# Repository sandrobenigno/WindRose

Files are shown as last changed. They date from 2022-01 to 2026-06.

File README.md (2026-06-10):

# The WindRose Project
Custom Hardware , Firmware and Software for Robotic Cellular Automata Experiments.

DOI (https://zenodo.org/badge/latestdoi/437105817)

### We’re used to hearing about evolution by competition, but what about thinking about things that evolve from cooperation?
<p>We can learn a lot about ourselves by simulating robotic beings communicating, sharing information, tools and interacting as a community of living beings. In these simulations, questions emerge such as the importance of synchronicity between beings, the need for a shared language for mutual understanding, among many other issues. That’s what this project and research is about.</p>

<p>Author: Sandro Benigno, due to the inspiration and all the applied resources from fellow professor Marilia Lyra Bergamo. She is the one who made this project possible and guided me with her research on Robotic Plants and Complexity Theories.</p>

### The Wiki Pages

<p>In the <a href="https://github.com/sandrobenigno/WindRose/wiki">wiki pages</a> you can learn about the board, including the pinout and its usage.</p>

### Code documentation
All the files and classes are <a target="_blank" rel="noopener noreferrer" href="https://sandrobenigno.github.io/WindRose/html/index.html">documented here</a>.

### Fabrication

<p>We fabricate the boards through Seeed Fusion PCB Assembly Service. Check how to <a href="https://github.com/sandrobenigno/WindRose/wiki/Fabricate-yours%21">fabricate yours!</a></p>

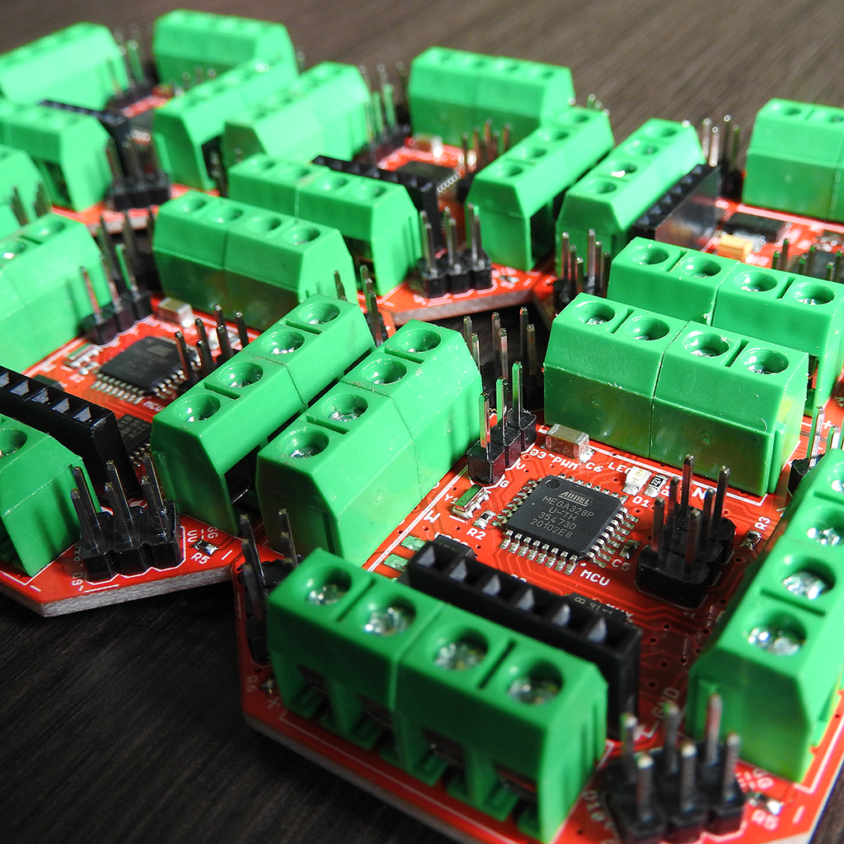
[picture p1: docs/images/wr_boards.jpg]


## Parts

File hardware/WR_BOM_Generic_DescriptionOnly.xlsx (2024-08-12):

Part | Value | Device | Package
C1 | 0.1uF | 0.1UF-0402-6.3V-10%-X7R | 0402
C2 | 47uF | 10UF-POLAR-EIA3216-16V-10%(TANT) | EIA3216
C3 | 0.1uF | 0.1UF-0402-6.3V-10%-X7R | 0402
C4 | 0.1uF | 0.1UF-0402-6.3V-10%-X7R | 0402
C5 | 0.1uF | 0.1UF-0402-6.3V-10%-X7R | 0402
C6 | 100uF | C-USC3216 | 3216
D1 | LED | LEDCHIP-LED0805 | 0805
D2 | SS24FL | DIODE-SOD123 | SOD123
MCU | ATMEGA328-AU | ATMEGA328-AU | QFP32_7X7_0.80
MUX | CD4051SSOP16 | CD4051SSOP16 | SSOP16
R1 | 220 | 220OHM-0603-1/10W-1% | 0603
R2 | 1M | R-US_R0402 | 0402
R3 | 10k | 10KOHM-0402-1/16W-1% | 0402
R4 | 10k | 10KOHM-0402-1/16W-1% | 0402
R5 | 10k | 10KOHM-0402-1/16W-1% | 0402
R6 | 10k | 10KOHM-0402-1/16W-1% | 0402
R7 | 10k | 10KOHM-0402-1/16W-1% | 0402
VREG |  | V_REG_AMS1117-5.0_SOT223 | SOT223
Y1 | 16MHz | RESONATOR-16MHZSMD_3.2X1.3 | RESONATOR-SMD-3.2X1.3

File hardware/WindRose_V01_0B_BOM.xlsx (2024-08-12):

Designator | Manufacturer Part Number or Seeed SKU | Qty | Link
C1,C3,C4,C5 | 302010037 | 4 | https://statics3.seeedstudio.com/fusion/opl/datasheet/302010037.pdf
C2 | 302020005 | 1 | https://statics3.seeedstudio.com/fusion/opl/datasheet/302020005.pdf
C6 | 302010183 | 1 | https://statics3.seeedstudio.com/fusion/opl/datasheet/302010183.pdf
D1 | 304090046 | 1 | https://statics3.seeedstudio.com/fusion/opl/datasheet/304090046.pdf
D2 | SS24FL | 1 | https://www.onsemi.com/pdf/datasheet/ss26fl-d.pdf
MCU | ATMEGA328P-AU | 1 | https://file.elecfans.com/web1/M00/BC/23/pIYBAF60v-CAX_3dAAs5XU5rfIc187.pdf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
MUX | CD4051BPWR | 1 | https://file.elecfans.com/web1/M00/9F/41/pIYBAF1AobyAUILsABdUm6BbdQU091.pdf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
R1 | RT0603DRD07220RL | 1 | https://file.elecfans.com/web2/M00/5A/77/poYBAGLrqhuANnZQAA8p9tNjF34381.pdf
R2 | 301010043 | 1 | https://statics3.seeedstudio.com/fusion/opl/datasheet/301010043.pdf
R3,R4,R5,R6,R7 | 301010047 | 5 | https://statics3.seeedstudio.com/fusion/opl/datasheet/301010047.pdf
VREG | AMS1117-5.0 | 1 | https://file.elecfans.com/web1/M00/8D/D9/o4YBAFyupoKAaMjDAALlu6SGvak196.pdf
Y1 | 306030002 | 1 | https://statics3.seeedstudio.com/fusion/opl/datasheet/306030002.pdf

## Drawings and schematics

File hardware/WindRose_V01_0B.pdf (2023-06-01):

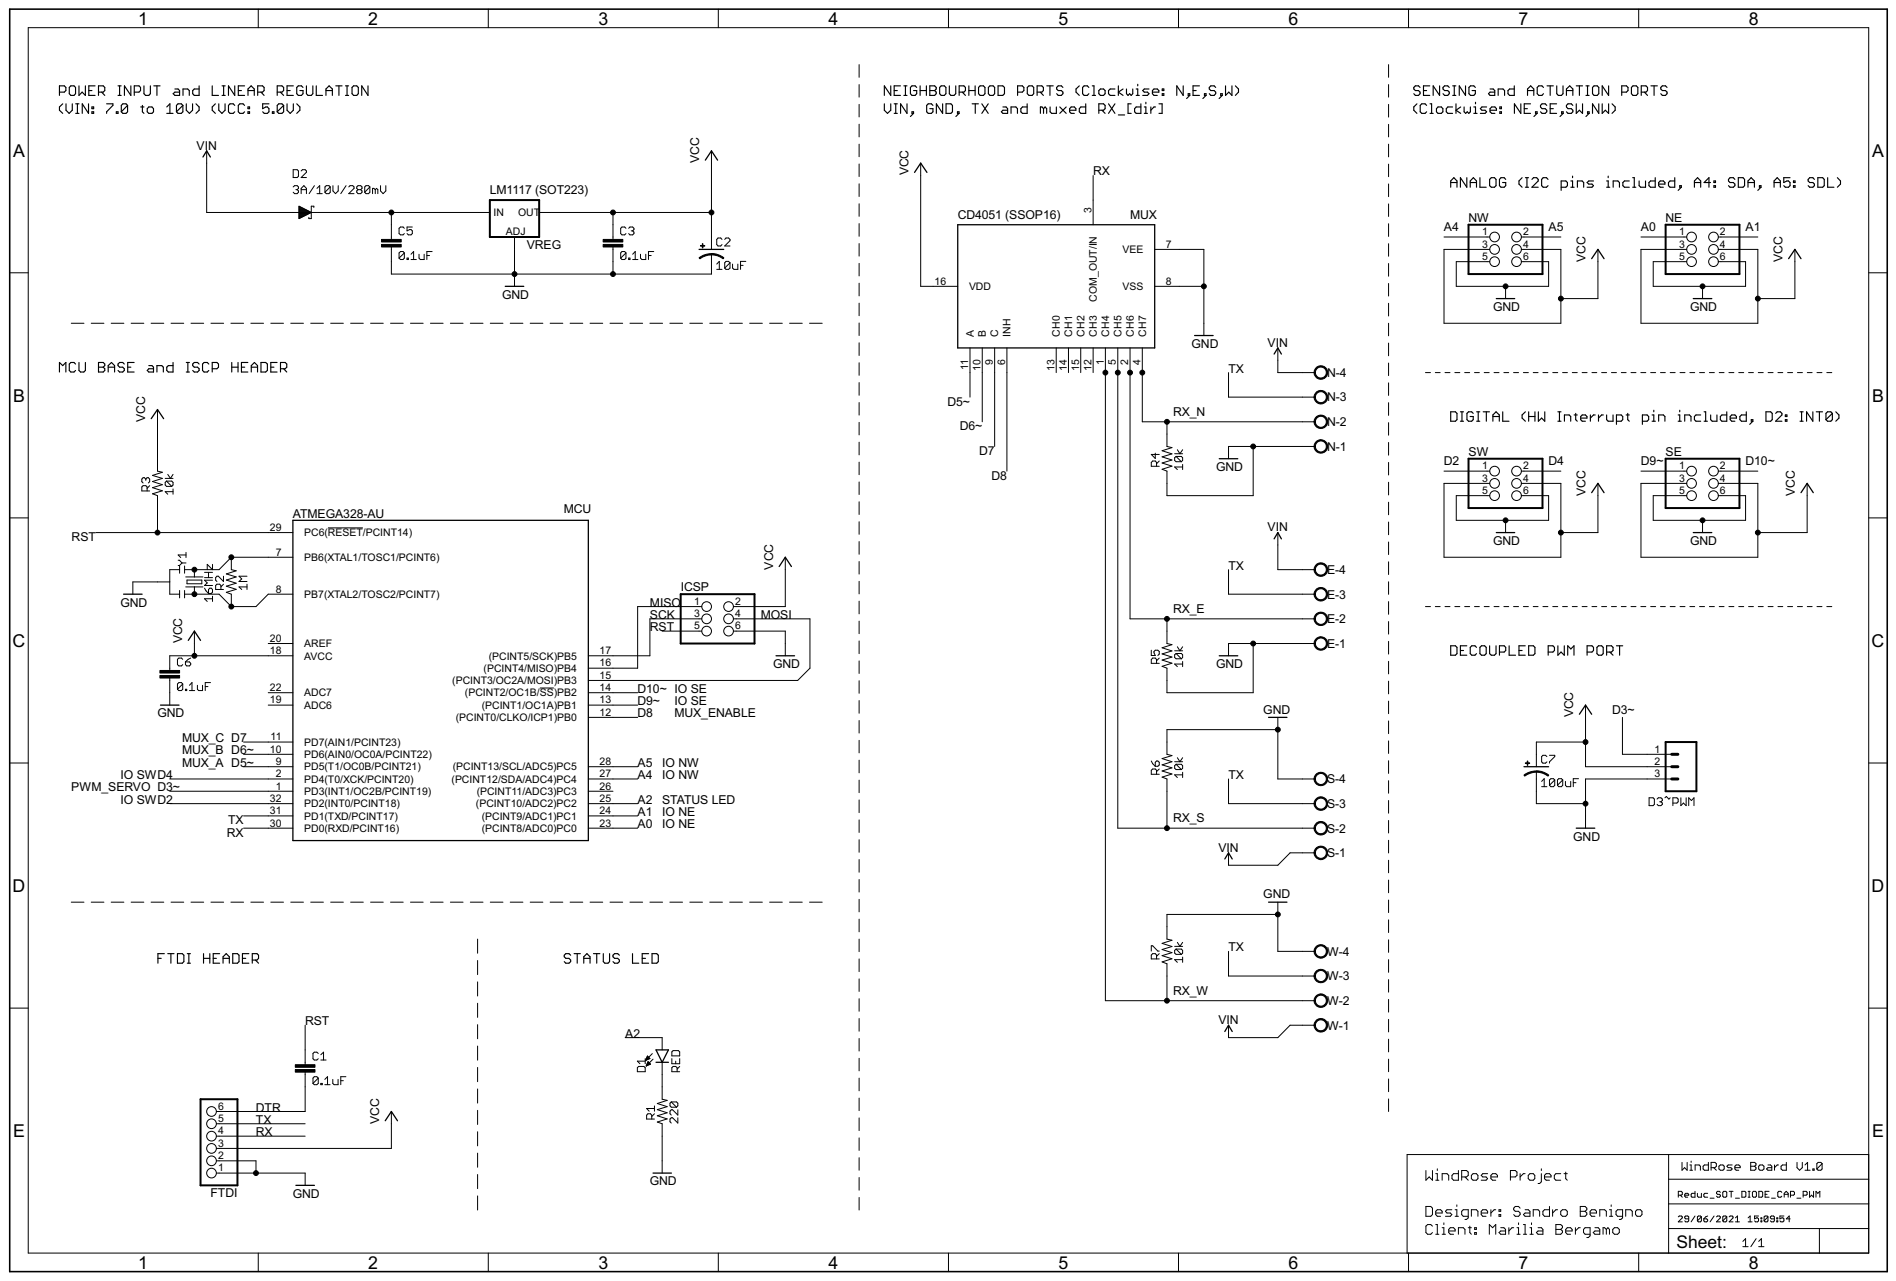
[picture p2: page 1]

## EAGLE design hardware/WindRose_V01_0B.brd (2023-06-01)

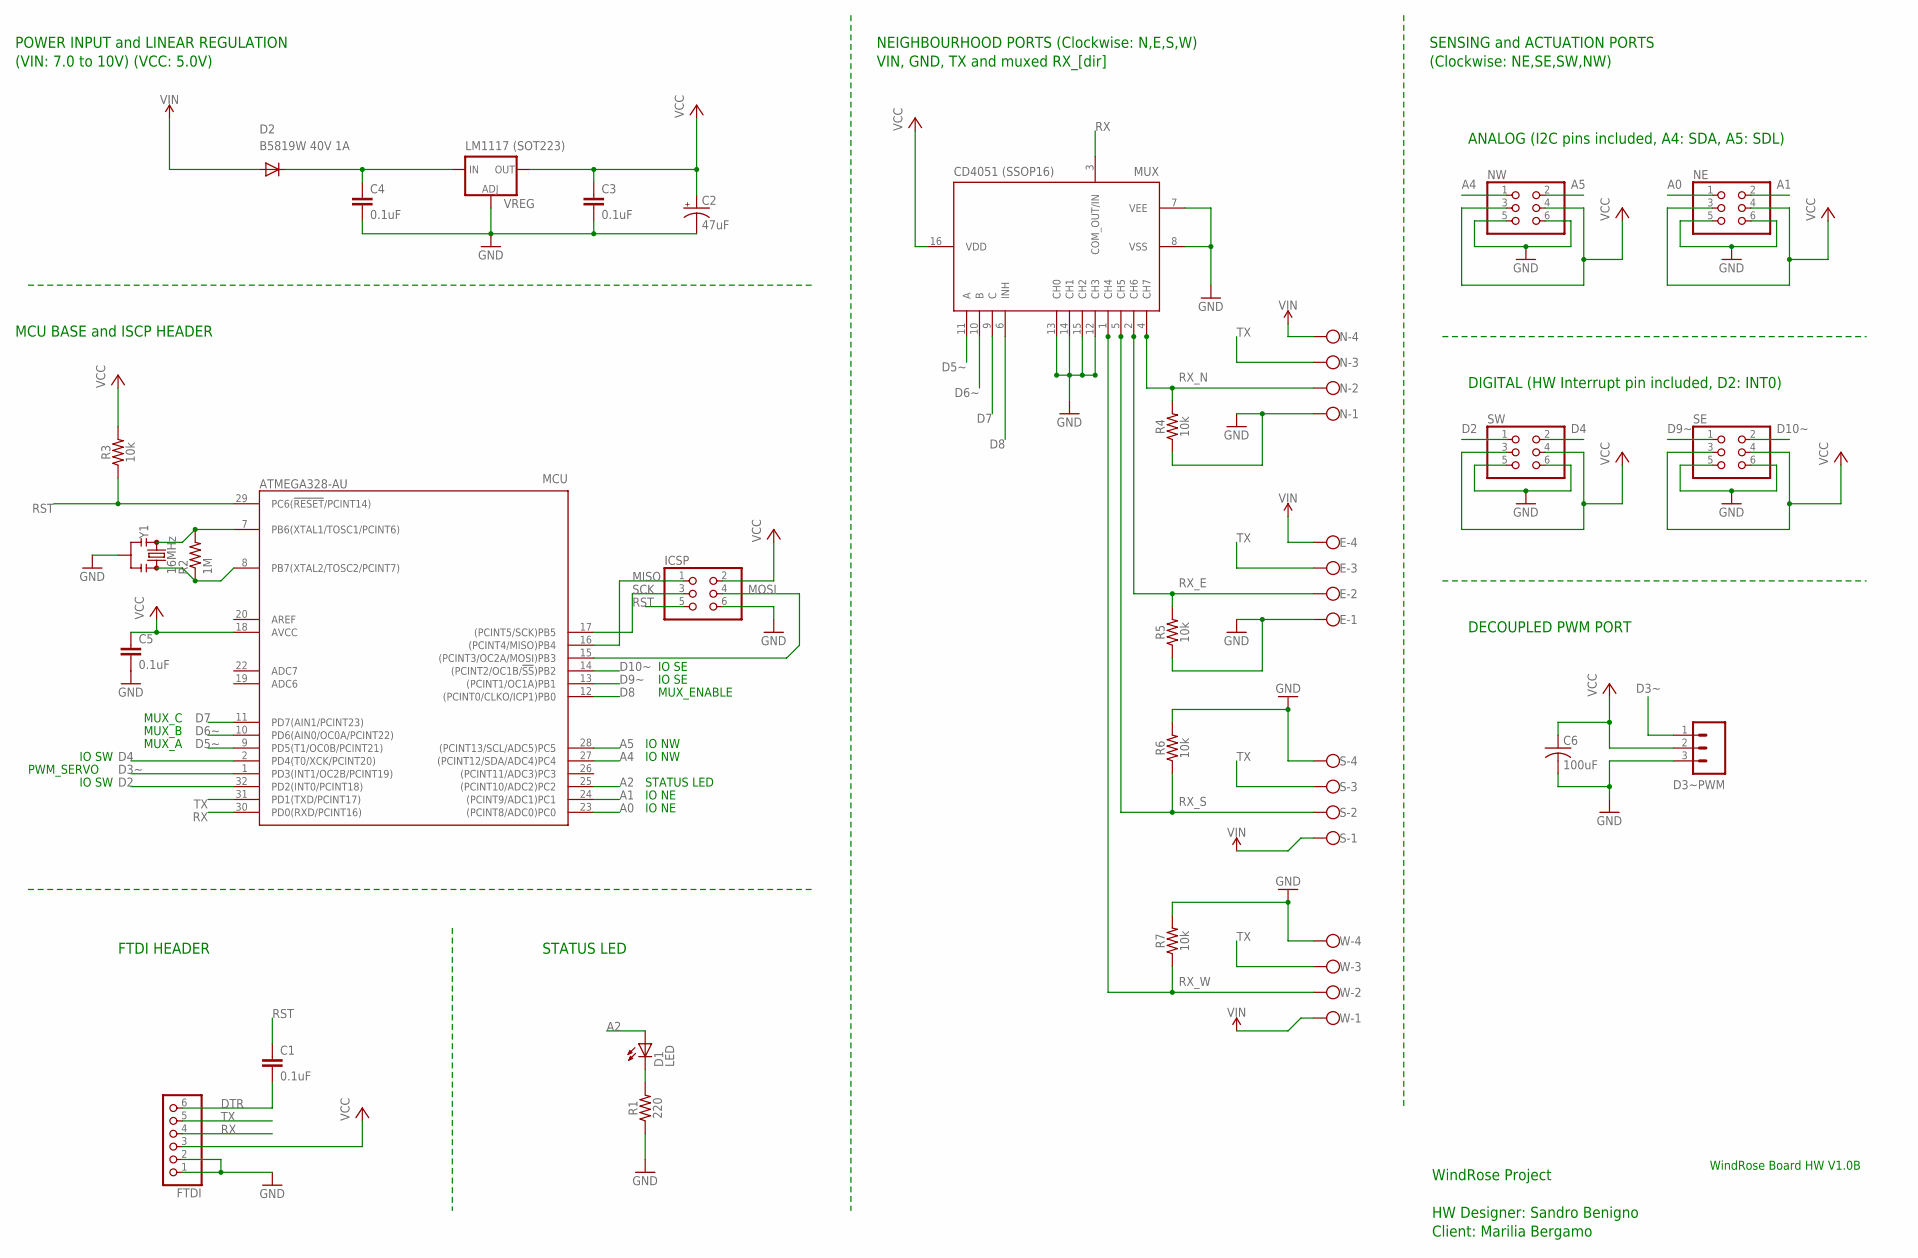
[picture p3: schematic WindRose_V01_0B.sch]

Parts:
C1, C3, C4, C5: 0.1uF; 0402
C2: 47uF; EIA3216
C6: 100uF; C3216
D1: LED; CHIP-LED0805
D2: B5819W 40V 1A; SOD123
D3~PWM: 455-1750-1-ND; 1X03
E: W237-4
FTDI: PINHD-1X6B; 1X06-BIG
ICSP: PINHD-2X3; 2X03
MCU: ATMEGA328-AU; QFP32_7X7_0.80
MUX: CD4051SSOP16; SSOP16
N: W237-4
NE: PINHD-2X3; 2X03
NW: PINHD-2X3; 2X03
R1: 220; 0603
R2: 1M; R0402
R3, R4, R5, R6, R7: 10k; 0402
S: W237-4
SE: PINHD-2X3; 2X03
SW: PINHD-2X3; 2X03
VREG: V_REG_LM1117SOT223; SOT223
W: W237-4
Y1: 16MHz; RESONATOR-SMD-3.2X1.3

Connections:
A0: MCU.23 ((PCINT8/ADC0)PC0), NE.1
A1: MCU.24 ((PCINT9/ADC1)PC1), NE.2
A2: D1.A, MCU.25 ((PCINT10/ADC2)PC2)
A4: MCU.27 ((PCINT12/SDA/ADC4)PC4), NW.1
A5: MCU.28 ((PCINT13/SCL/ADC5)PC5), NW.2
D2: MCU.32 (PD2(INT0/PCINT18)), SW.1
D3~: D3~PWM.1, MCU.1 (PD3(INT1/OC2B/PCINT19))
D4: MCU.2 (PD4(T0/XCK/PCINT20)), SW.2
D5~: MCU.9 (PD5(T1/OC0B/PCINT21)), MUX.11 (A)
D6~: MCU.10 (PD6(AIN0/OC0A/PCINT22)), MUX.10 (B)
D7: MCU.11 (PD7(AIN1/PCINT23)), MUX.9 (C)
D8: MCU.12 ((PCINT0/CLKO/ICP1)PB0), MUX.6 (INH)
D9~: MCU.13 ((PCINT1/OC1A)PB1), SE.1
D10~: MCU.14 ((PCINT2/OC1B/!SS!)PB2), SE.2
DTR: C1.2, FTDI.6
GND: C2.-, C3.2, C4.2, C5.2, C6.2, D3~PWM.3, E.1, FTDI.1, FTDI.2, ICSP.6, MCU.3 (GND), MCU.5 (GND), MCU.21 (GND), MUX.7 (VEE), MUX.8 (VSS), MUX.12 (CH3), MUX.13 (CH0), MUX.14 (CH1), MUX.15 (CH2), N.1, NE.5, NE.6, NW.5, NW.6, R1.1, R4.1, R5.1, R6.2, R7.2, S.4, SE.5, SE.6, SW.5, SW.6, VREG.1 (ADJ), W.4, Y1.2
MISO: ICSP.1, MCU.16 ((PCINT4/MISO)PB4)
MOSI: ICSP.4, MCU.15 ((PCINT3/OC2A/MOSI)PB3)
unnamed: MCU.8 (PB7(XTAL2/TOSC2/PCINT7)), R2.1, Y1.3
unnamed: MCU.7 (PB6(XTAL1/TOSC1/PCINT6)), R2.2, Y1.1
unnamed: D1.C, R1.2
unnamed: C4.1, D2.C, VREG.3 (IN)
RST: C1.1, ICSP.5, MCU.29 (PC6(!RESET!/PCINT14)), R3.1
RX: FTDI.4, MCU.30 (PD0(RXD/PCINT16)), MUX.3 (COM_OUT/IN)
RX_E: E.2, MUX.2 (CH6), R5.2
RX_N: MUX.4 (CH7), N.2, R4.2
RX_S: MUX.5 (CH5), R6.1, S.2
RX_W: MUX.1 (CH4), R7.1, W.2
SCK: ICSP.3, MCU.17 ((PCINT5/SCK)PB5)
TX: E.3, FTDI.5, MCU.31 (PD1(TXD/PCINT17)), N.3, S.3, W.3
VCC: C2.+, C3.1, C5.1, C6.1, D3~PWM.2, FTDI.3, ICSP.2, MCU.4 (VCC), MCU.6 (VCC), MCU.18 (AVCC), MUX.16 (VDD), NE.3, NE.4, NW.3, NW.4, R3.2, SE.3, SE.4, SW.3, SW.4, VREG.2 (OUT), VREG.4 (OUT)
VIN: D2.A, E.4, N.4, S.1, W.1

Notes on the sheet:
PWM_SERVO
MUX_A
MUX_B
MUX_C
IO SW
IO NE
IO NW
IO SE
MUX_ENABLE
STATUS LED
POWER INPUT and LINEAR REGULATION (VIN: 7.0 to 10V) (VCC: 5.0V)
NEIGHBOURHOOD PORTS (Clockwise: N,E,S,W) VIN, GND, TX and muxed RX_[dir]
SENSING and ACTUATION PORTS (Clockwise: NE,SE,SW,NW)
FTDI HEADER
MCU BASE and ISCP HEADER
DECOUPLED PWM PORT
WindRose Project HW Designer: Sandro Benigno Client: Marilia Bergamo
WindRose Board HW V1.0B
ANALOG (I2C pins included, A4: SDA, A5: SDL)
DIGITAL (HW Interrupt pin included, D2: INT0)
CD4051 (SSOP16)
LM1117 (SOT223)
MUX

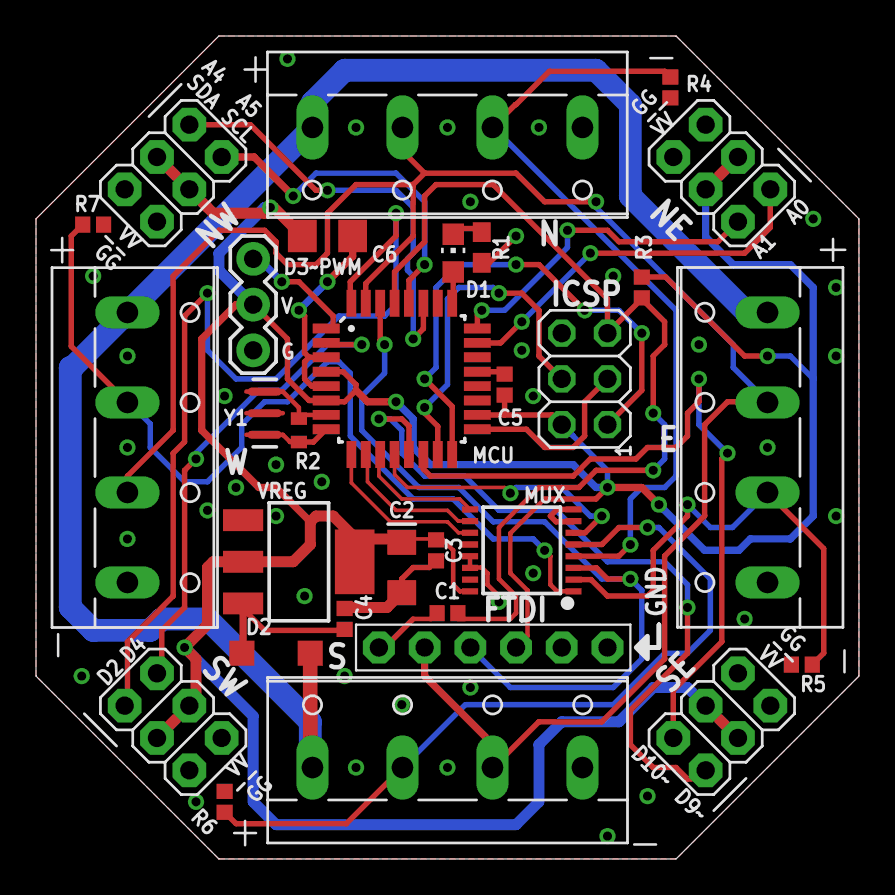
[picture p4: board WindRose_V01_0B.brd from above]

Board: 2 copper layers, 45.7 x 45.7 mm, 31 parts (1 on the bottom side), 32 nets.

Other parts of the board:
U$1: WINDROSE_LOGO

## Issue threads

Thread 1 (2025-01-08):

Lost Code // Maintainance with system on

marilialb, 2025-01-08:
When you disconnect a cable between the N/S/W/E previously connected, the system loses the firmware and needs to be rebooted with the boot.

And if you update only the boot on the one that lost the connection, you learn that all the boards connected to that one will also lose the boot. The only way to establish the system is to start rebooting from the corners to the middle of the system.

marilialb, 2025-01-08:
Always turn the system off (out of power source) before maintaining any connection cable.

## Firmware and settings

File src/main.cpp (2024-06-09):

/** 
 * @file main.cpp
 * @brief This file implements the setup and loop of a WindRose board as a cellular automaton.
 * @details The main.cpp file imports the headers of the two main classes of the project. \n
 * The class WRBoard is the body of the WindRose cell ,as it controls the multiplexer, the LEDs and runs the Serial State Machine. \n
 * The class Being represents the cell's being. It's the soul of each WindRose cell and drives the sensing data.
 * @author Sandro Benigno, thanks to fellow professor Marilia Lyra Bergamo for the inspirartion and all the applied resources. \n
 * She is the one who made this project possible and inspired us by her research on Robotic Plants and Complexity Theories.
 * @version 2.0
 * @date 2024-06-09
 */

#include <Arduino.h> //Arduino header
#include "Config.h" //Config header
#include "WindRose.h" //The body: The WindRose Board classes (State Machine, Mux, LED etc)
#include "Being.h" //The soul: The Being class for holding and driving the sensing data
#include "Circadian.h" //Circadian class for internal loopings at specified periods

/** @brief WRBoard instance for driving the Multiplexer, the LED and the Serial State Machine (the body). */
WRBoard wr; //The WindRose board object
/** @brief Being instance for holding and driving the sensing data (the soul). */
Being mySelf; //The current cell
/** @brief The array of Being instances for holding and driving the sensing data of the neighbours. */
Being ngHood[4]; //The four neighbours 

/** @brief The circadian cycle for reading the serial buffer through the Serial State Machine. */
Circadian cycle_buffering(300); //The time the automata has been buffering

void setup() {

  wr.init(WRBAUDRATE); //Initialize the board setting the baud rate
  wr.led.off(); //Turn off the LED
  wr.mux.setDir(N); //Set the mux to the north edge
  wr.mux.enable(); //Enable the WindRose Mux
  delay(100); //Wait for the serial buffer to get some data

  mySelf.born(); //Set the WindRose being to be alive (the breath of life)

  //Sensor initialization
  pinMode(A0, INPUT); //Set the A0 pin as input
  //Activate Sensors means to set which sensors would be broadcasted
  mySelf.activate(light); //Activate the light sensor
  mySelf.activate(wind); //Activate the wind sensor
  mySelf.activate(coord); //Activate the coordinate sensor
}

void loop() {
  
  // Sensor Reading Block //////////////////////////////////////////////////////
  /** @brief The sensor reading block for reading the sensors and store it in the Being instance. */

  mySelf.sensors.light.lux = analogRead(A0); //Read the light sensor
  //mySelf.sensors.light.lux = ngHood[W].sensors.light.lux; //Borrowing the light sensor from the west neighbour
  mySelf.sensors.light.temp = 3200; //Set the color temperature to 3200 Kelvin

  mySelf.sensors.coord.x = millis(); //Set the x coordinate to the current time
  mySelf.sensors.coord.y = millis()/2; //Set the y coordinate to the current time

  mySelf.sensors.wind.speed = int(sin(float(millis() / 10000.0)) * 1000); //Set the x coordinate to the current time
  mySelf.sensors.wind.dir = millis()/4; //Set the y coordinate to the current time

  mySelf.updateAge(); //Update myself Age 
  
  // Comunication Block //////////////////////////////////////////////////////
  /** @brief The communication block for 1) receiving the neighbours data and 2) sending the myself data to the neighbours*/

  if(cycle_buffering.isElapsed()) // Buffer the data following a circadian cycle before processing the collected data
  {
    wr.ssm.getData(&ngHood[wr.mux.getDir()]);//Get sensing data from the neighbour
    mySelf.updateNGS(ngHood); //Update the Neighbouthood Mapping  
    mySelf.calcDNGS(ngHood); //Inferring diagonal neighbours

    //Changing the direction of the mux to the next neighbour
    wr.mux.disable(); //Disable the WindRose Mux
    wr.ssm.clearBuffer(); //Clear the buffer
    wr.mux.next(); //Move to the next edge
    wr.mux.enable(); //Enable the WindRose Mux

    wr.led.toggle(); //Toggle the LED
  }
  else if(mySelf.alive) { // Keep transmitting data until the data buffering cycle is enlapsed
    wr.ssm.sendData(&mySelf); //sending data while buffering
  }
}

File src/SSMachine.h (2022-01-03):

/** 
 * @file SSMachine.h
 * @brief This file defines the WindRose's Serial State Machine Control class SSMachine.
 * @author Sandro Benigno
 * @version 1.0
 * @date 2020-01-01
 */

#ifndef SSMachine_h
#define SSMachine_h

#include "Config.h" //Config header
#include "Sensing.h"
#include "Being.h"
#include "WRMux.h"

/** 
 * @brief The class to control the Serial State Machine.
 * @details The SSMachine class holds the functions related to the Serial State Machine. \n
  It grabs the data of the Neighbors Sensing, and sends itself data through the Serial port. \n
  We dont call it directly, instead we call it from the class WRBoard as <ssm>.
 */
class SSMachine
{
  private:
    Stream *_stmRef; // Stream reference object
    WRMux _mux; //Multiplexer controller
    uint8_t ck_a=0; //Checksum accumulator A
    uint8_t ck_b=0; //Checksum accumulator B
  public:
    boolean trustpack = false; //Flag to indicate if the packet is trusted
    uint32_t lostpack = 0; //Number of lost packets

    /**
     * @brief Initializes the Serial State Machine by setting its internal Stream object to a pointer to the Serial Hardware instance.
     * @param *stmObject A pointer to the Serial Hardware instance.
     */
    void setSerial(Stream *stmObject)
    {
      this->_stmRef=stmObject; //Set the reference to the serial port
    }
    
    /**
     * @brief Prints the Lost Packets counter to the Serial port.
     */
    void printLostPack()
    {
      this->_stmRef->print("Lost packets: ");
      this->_stmRef->println(this->lostpack);
    }

    /**
     * @brief Clears the Serial Buffer.
     */
    void clearBuffer()
    {
      while (this->_stmRef->available()) this->_stmRef->read(); //Clearing the Serial buffer
    }

    /**
     * @brief Sends the data of the itself Sensing data to the Serial port.
     * @param *me pointer to itself Being object.
     */
    void sendData(Being *me)
    {
      byte DATA_buffer[MAX_SENSING_BYTES_PER_PACKET + 8]; // All sensors + 4 ASBM + 4 Lifetime
      uint8_t ck = 0; //Byte checksum accumulator
      byte CRC_ck_a = 0x06; //Checksum accumulator A (Starting by the seed A)
      byte CRC_ck_b = 0x02; //Checksum seed B (Starting by the seed B)

      //HERE IS THE PACKET HEADER (6 bytes)

      this->_stmRef->write("WRoS"); //Write the header
      this->_stmRef->write(CRC_ck_a); //Write the seed A
      this->_stmRef->write(CRC_ck_b); //Write the seed B

      //HERE STARTS THE PAYLOAD OF THE PACKET

      //Write the Neighborhood Mapping
      DATA_buffer[ck] = me->NGS; //Write the NGS
      ck +=1;

      //Write the Being Age (4 bytes)
      me->age = millis(); //Time since start running
      DATA_buffer[ck] = byte(me->age >> 24 & 0xFF);
      DATA_buffer[ck+1] = byte(me->age >> 16 & 0xFF);
      DATA_buffer[ck+2] = byte(me->age >> 8 & 0xFF);
      DATA_buffer[ck+3] = byte(me->age & 0xFF);
      ck += 4;      

      //Write the ASBM (4 bytes)
      DATA_buffer[ck] = byte(me->ASBM >> 24 & 0xFF);
      DATA_buffer[ck+1] = byte(me->ASBM >> 16 & 0xFF);
      DATA_buffer[ck+2] = byte(me->ASBM >> 8 & 0xFF);
      DATA_buffer[ck+3] = byte(me->ASBM & 0xFF);
      ck += 4;

      //HERE STARTS THE DYNAMIC SENSOR REPORTING

      //Check the ASBM and write the data for Coordinates Sensor
      if(me->isactive(coord)){ //Coord_t
        DATA_buffer[ck] = byte(me->sensors.coord.x >> 8 & 0xFF);
        DATA_buffer[ck+1] = byte(me->sensors.coord.x & 0xFF);
        DATA_buffer[ck+2] = byte(me->sensors.coord.y >> 8 & 0xFF);
        DATA_buffer[ck+3] = byte(me->sensors.coord.y & 0xFF);
        DATA_buffer[ck+4] = byte(me->sensors.coord.z >> 8 & 0xFF);
        DATA_buffer[ck+5] = byte(me->sensors.coord.z & 0xFF);
        ck += 6;
      }

      //Check the ASBM and write the data for Angle Sensor
      if(me->isactive(angle)){ //Angle_t
        DATA_buffer[ck] = byte(me->sensors.angle.pitch >> 8 & 0xFF);
        DATA_buffer[ck+1] = byte(me->sensors.angle.pitch & 0xFF);
        DATA_buffer[ck+2] = byte(me->sensors.angle.roll >> 8 & 0xFF);
        DATA_buffer[ck+3] = byte(me->sensors.angle.roll & 0xFF);
        DATA_buffer[ck+4] = byte(me->sensors.angle.yaw >> 8 & 0xFF);
        DATA_buffer[ck+5] = byte(me->sensors.angle.yaw & 0xFF);
        ck += 6;
      }

      //Check the ASBM and write the data for Accelerometer Sensor
      if(me->isactive(accel)){ //Accel_t
        DATA_buffer[ck] = byte(me->sensors.accel.x >> 8 & 0xFF);
        DATA_buffer[ck+1] = byte(me->sensors.accel.x & 0xFF);
        DATA_buffer[ck+2] = byte(me->sensors.accel.y >> 8 & 0xFF);
        DATA_buffer[ck+3] = byte(me->sensors.accel.y & 0xFF);
        DATA_buffer[ck+4] = byte(me->sensors.accel.z >> 8 & 0xFF);
        DATA_buffer[ck+5] = byte(me->sensors.accel.z & 0xFF);
        ck += 6;
      }

      //Check the ASBM and write the data for Gyroscope Sensor
      if(me->isactive(ang_rate)){ //Ang_rate_t
        DATA_buffer[ck] = byte(me->sensors.ang_rate.x >> 8 & 0xFF);
        DATA_buffer[ck+1] = byte(me->sensors.ang_rate.x & 0xFF);
        DATA_buffer[ck+2] = byte(me->sensors.ang_rate.y >> 8 & 0xFF);
        DATA_buffer[ck+3] = byte(me->sensors.ang_rate.y & 0xFF);
        DATA_buffer[ck+4] = byte(me->sensors.ang_rate.z >> 8 & 0xFF);
        DATA_buffer[ck+5] = byte(me->sensors.ang_rate.z & 0xFF);
        ck += 6;
      }

      //Check the ASBM and write the data for GPS Sensor
      if(me->isactive(gps_pos)){ //GPS_pos_t
        DATA_buffer[ck] = byte(me->sensors.gps_pos.lat >> 24 & 0xFF);
        DATA_buffer[ck+1] = byte(me->sensors.gps_pos.lat >> 16 & 0xFF);
        DATA_buffer[ck+2] = byte(me->sensors.gps_pos.lat >> 8 & 0xFF);
        DATA_buffer[ck+3] = byte(me->sensors.gps_pos.lat & 0xFF);
        DATA_buffer[ck+4] = byte(me->sensors.gps_pos.lon >> 24 & 0xFF);
        DATA_buffer[ck+5] = byte(me->sensors.gps_pos.lon >> 16 & 0xFF);
        DATA_buffer[ck+6] = byte(me->sensors.gps_pos.lon >> 8 & 0xFF);
        DATA_buffer[ck+7] = byte(me->sensors.gps_pos.lon & 0xFF);
        DATA_buffer[ck+8] = byte(me->sensors.gps_pos.alt >> 24 & 0xFF);
        DATA_buffer[ck+9] = byte(me->sensors.gps_pos.alt >> 16 & 0xFF);
        DATA_buffer[ck+10] = byte(me->sensors.gps_pos.alt >> 8 & 0xFF);
        DATA_buffer[ck+11] = byte(me->sensors.gps_pos.alt & 0xFF);
        DATA_buffer[ck+12] = byte(me->sensors.gps_pos.gspeed >> 24 & 0xFF);
        DATA_buffer[ck+13] = byte(me->sensors.gps_pos.gspeed >> 16 & 0xFF);
        DATA_buffer[ck+14] = byte(me->sensors.gps_pos.gspeed >> 8 & 0xFF);
        DATA_buffer[ck+15] = byte(me->sensors.gps_pos.gspeed & 0xFF);
        ck += 16;
      }

      //Check the ASBM and write the data for Barometer Sensor
      if(me->isactive(wind)){ //Wind_t
        DATA_buffer[ck] = byte(me->sensors.wind.speed >> 8 & 0xFF);
        DATA_buffer[ck+1] = byte(me->sensors.wind.speed & 0xFF);
        DATA_buffer[ck+2] = byte(me->sensors.wind.dir >> 8 & 0xFF);
        DATA_buffer[ck+3] = byte(me->sensors.wind.dir & 0xFF);
        ck += 4;
      }
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

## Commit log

2021-12-11 Fixing hardcoded directives and config issues
    [SSMachine.h, main.cpp]
2021-12-11 Fixing comments and the maximum DATA_buffer size
    [SSMachine.h]
2021-12-31 Bug fixing and updates
    [DrawFunctions.pde, SSMachine.h, StateMachine.pde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]
2022-08-16 LED set as off on setup block and few comments added
2023-06-01 Adding the hardware files
    [WindRose_V01_0B.brd, WindRose_V01_0B.sch, WindRose_V01_0B_BOM.xlsx]
2024-08-12 Updated BOM and added a generic, more descriptive version
    [WR_BOM_Generic_DescriptionOnly.xlsx, WindRose_V01_0B_BOM.xlsx]

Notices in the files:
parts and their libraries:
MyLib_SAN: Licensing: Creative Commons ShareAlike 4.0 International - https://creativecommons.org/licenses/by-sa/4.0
